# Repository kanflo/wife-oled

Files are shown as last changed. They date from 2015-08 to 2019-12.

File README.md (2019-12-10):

**Wife OLED**
==========

I wanted a display showing the current outside temperature alongside with the forecasted temperature in 8 hours.

The device subscribes to the topics `home/temperature/outside` and `home/temperature/forecast` displaying them in the left and right part of the display respectively. For readability I use a large font, [Ubuntu Condensed](http://font.ubuntu.com/#charset-condensed) in sizes 32px and 28px.

**Building**

Clone this repo:

```
git clone https://github.com/kanflo/wife-oled.git
cd wife-oled
git submodule init && git submodule update

```

Set the SSID configuration of EOR by adding the following to the file ```esp-open-rtos/include/private_ssid_config.h```:

```
#define WIFI_SSID "my ssid"
#define WIFI_PASS "my password"
```

Configure the MQTT stuff in ```mqtt_config.h```

Now ```make``` and ```make flash```

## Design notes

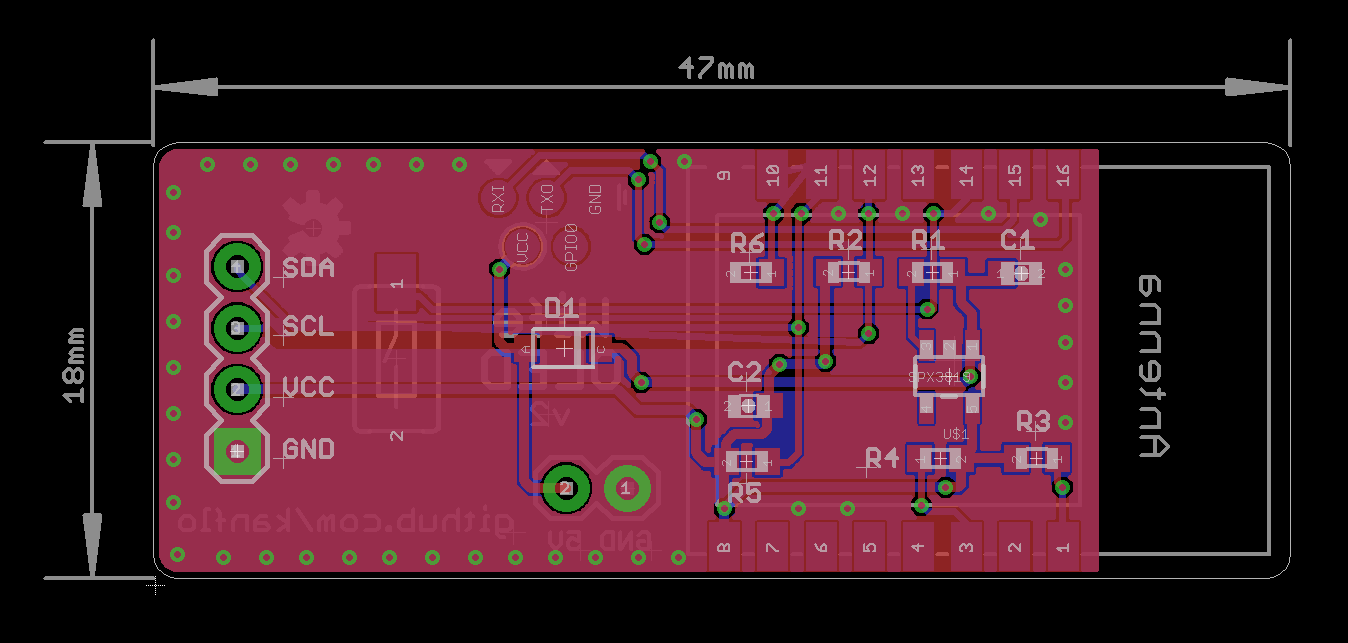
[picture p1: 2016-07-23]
hardware/WifeOLED-v2/WifeOLED-v2.png

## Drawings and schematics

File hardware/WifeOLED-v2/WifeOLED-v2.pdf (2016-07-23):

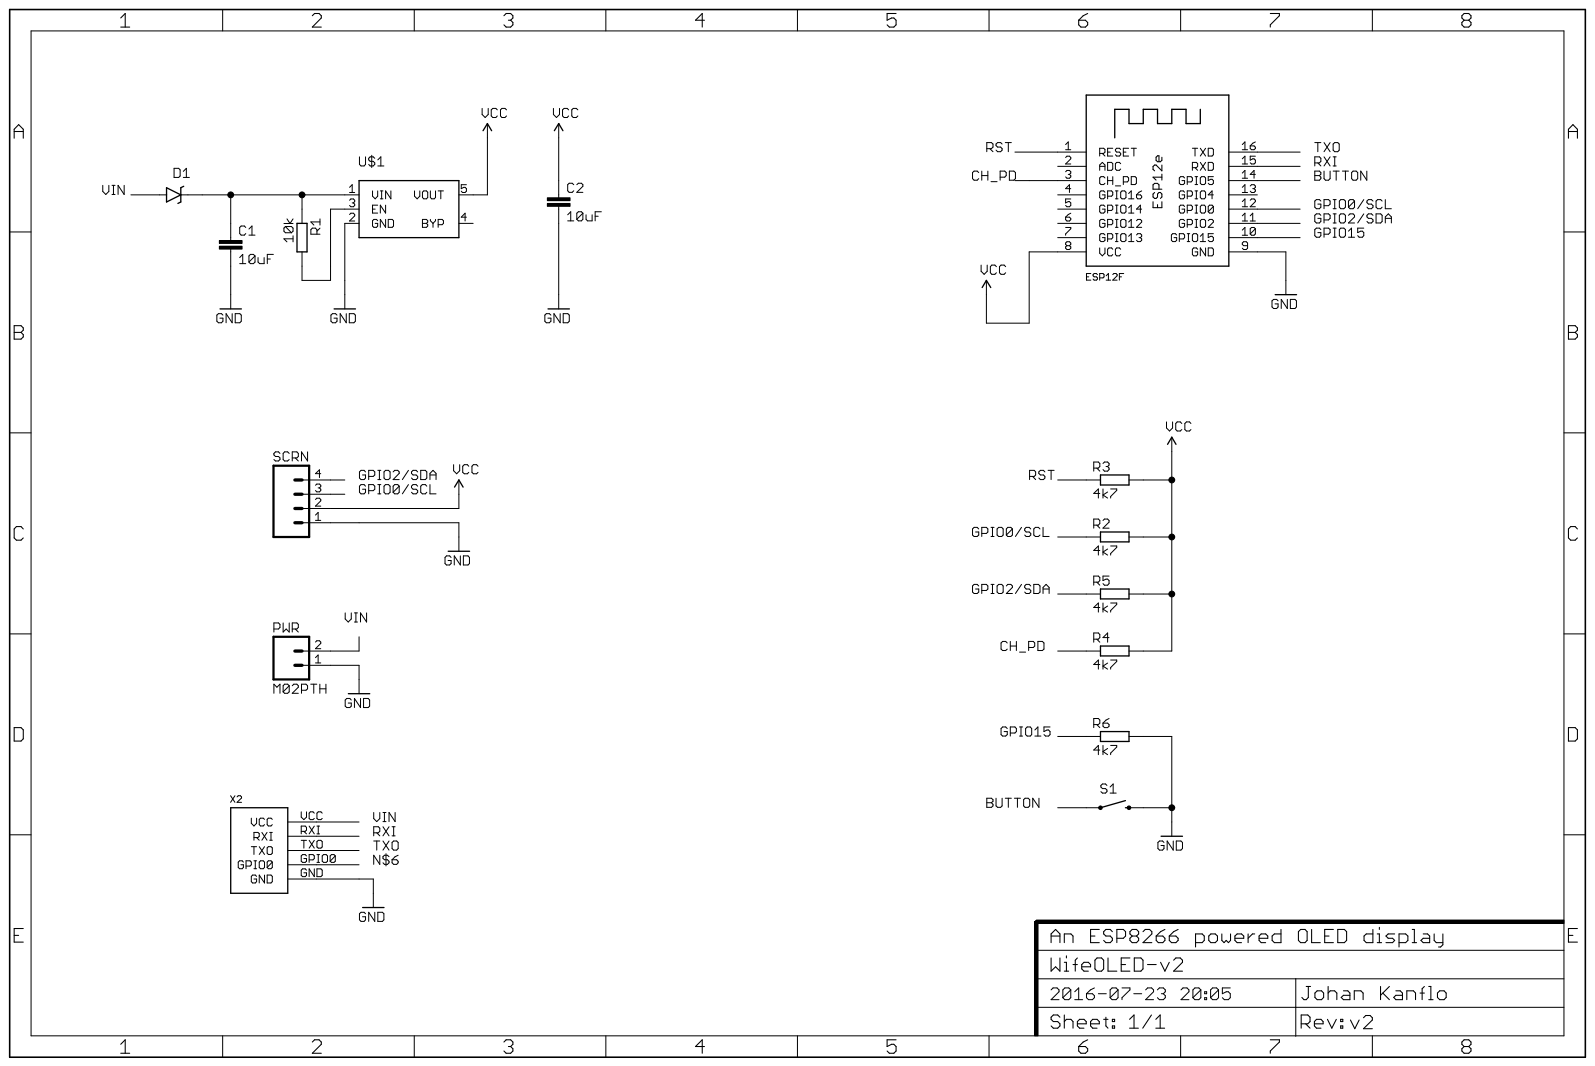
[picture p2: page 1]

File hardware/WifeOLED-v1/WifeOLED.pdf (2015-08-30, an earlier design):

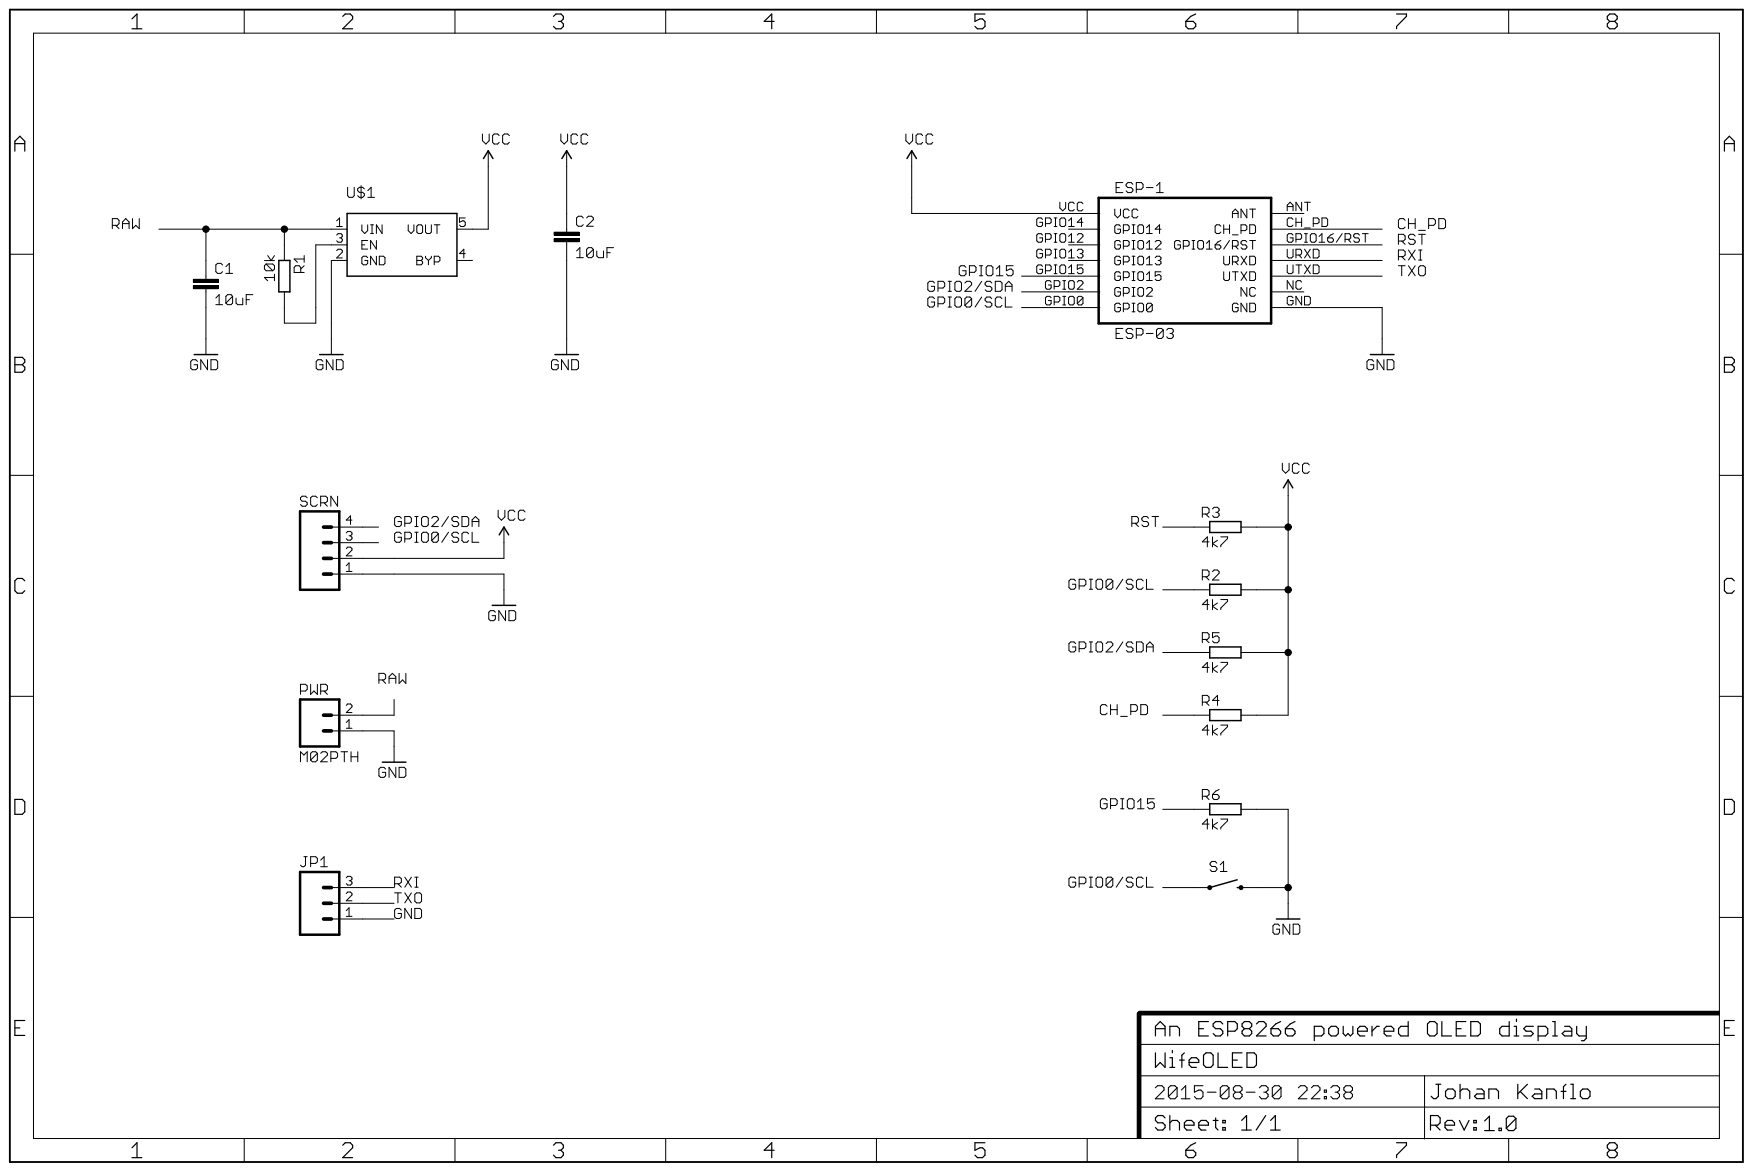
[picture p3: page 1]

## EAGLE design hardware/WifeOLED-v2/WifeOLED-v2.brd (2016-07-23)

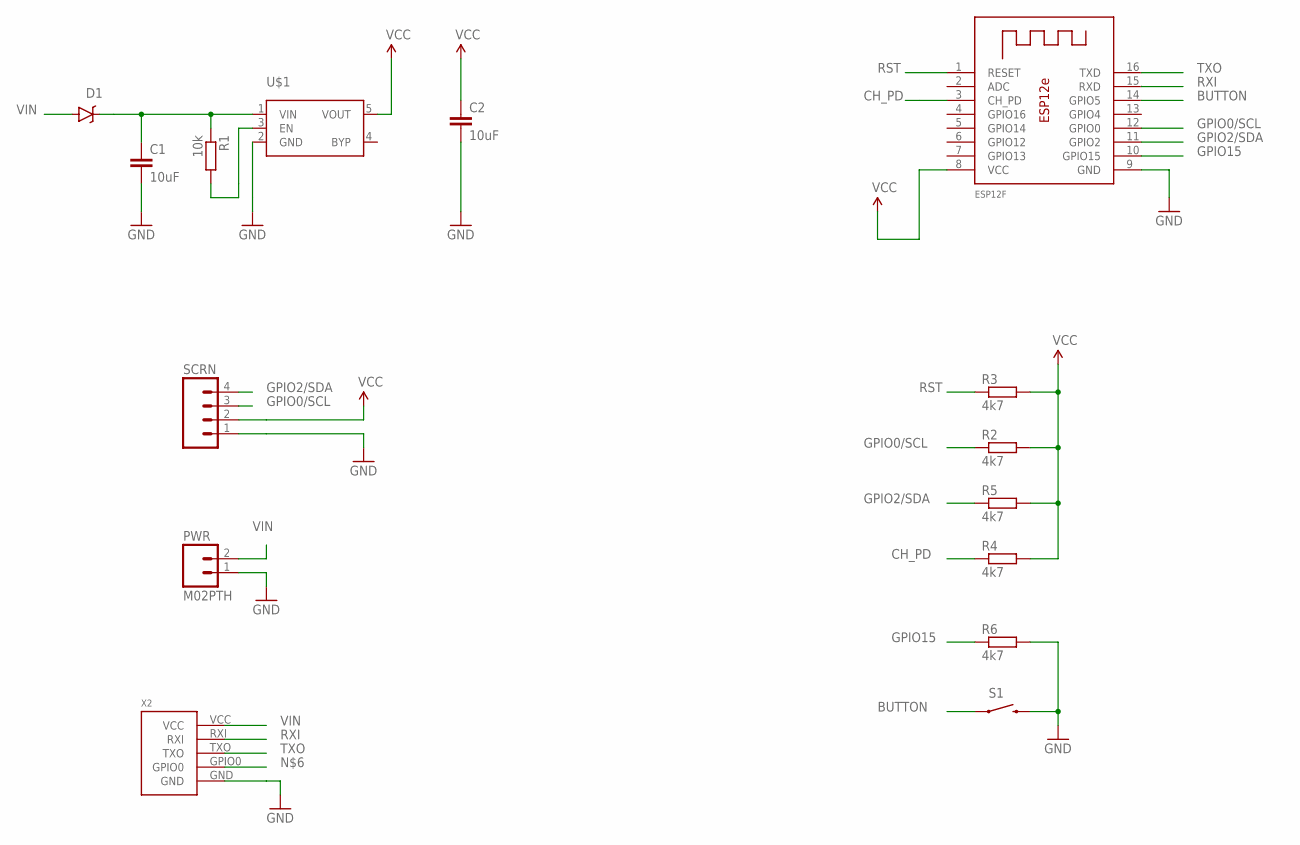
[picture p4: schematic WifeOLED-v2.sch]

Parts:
C1, C2: 10uF; 0603-CAP
D1: DIODE-SCHOTTKYSOD-123FL; SOD-123FL
ESP12F: ESP-12E
PWR: M02PTH; 1X02
R1: 10k; R0603
R2, R3, R4, R5, R6: 4k7; R0603
S1: SWITCH-MOMENTARY-2SMD-1101NE; TACTILE-SWITCH-1101NE
SCRN: M04PTH; 1X04
U$1: SPX3819; SOT23-5
X2: ESPROGESPROG-DEVICE; ESPROG

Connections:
BUTTON: ESP12F.14 (GPIO5), S1.1
CH_PD: ESP12F.3 (CH_PD), R4.1
GND: C1.2, C2.2, ESP12F.9 (GND), PWR.1, R6.2, S1.2, SCRN.1, U$1.2 (GND), X2.GND
GPIO0/SCL: ESP12F.12 (GPIO0), R2.1, SCRN.3
GPIO2/SDA: ESP12F.11 (GPIO2), R5.1, SCRN.4
GPIO15: ESP12F.10 (GPIO15), R6.1
unnamed: R1.2, U$1.3 (EN)
unnamed: C1.1, D1.C, R1.1, U$1.1 (VIN)
RST: ESP12F.1 (RESET), R3.1
RXI: ESP12F.15 (RXD), X2.RXI
TXO: ESP12F.16 (TXD), X2.TXO
VCC: C2.1, ESP12F.8 (VCC), R2.2, R3.2, R4.2, R5.2, SCRN.2, U$1.5 (VOUT)
VIN: D1.A, PWR.2, X2.VCC

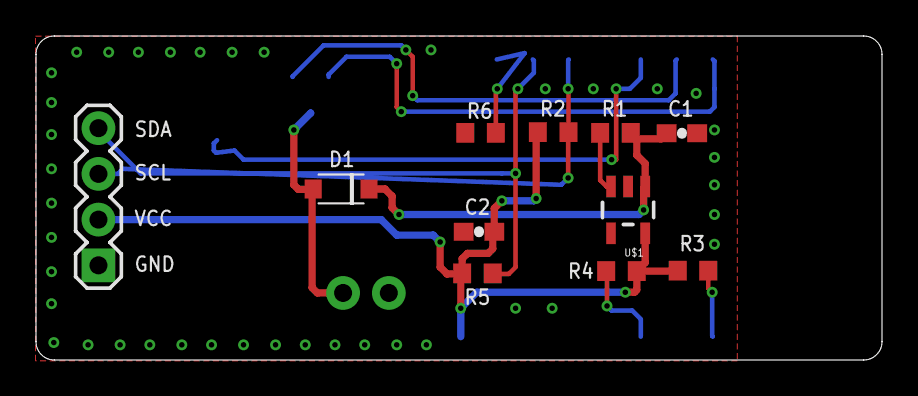
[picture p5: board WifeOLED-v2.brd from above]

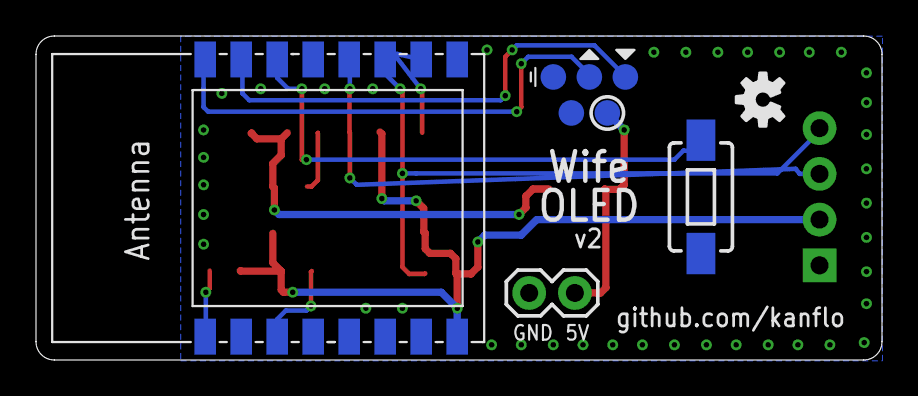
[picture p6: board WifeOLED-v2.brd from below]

Board: 2 copper layers, 47.0 x 18.0 mm, 16 parts (5 on the bottom side), 13 nets.

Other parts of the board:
U$2: OSHW-LOGO-S

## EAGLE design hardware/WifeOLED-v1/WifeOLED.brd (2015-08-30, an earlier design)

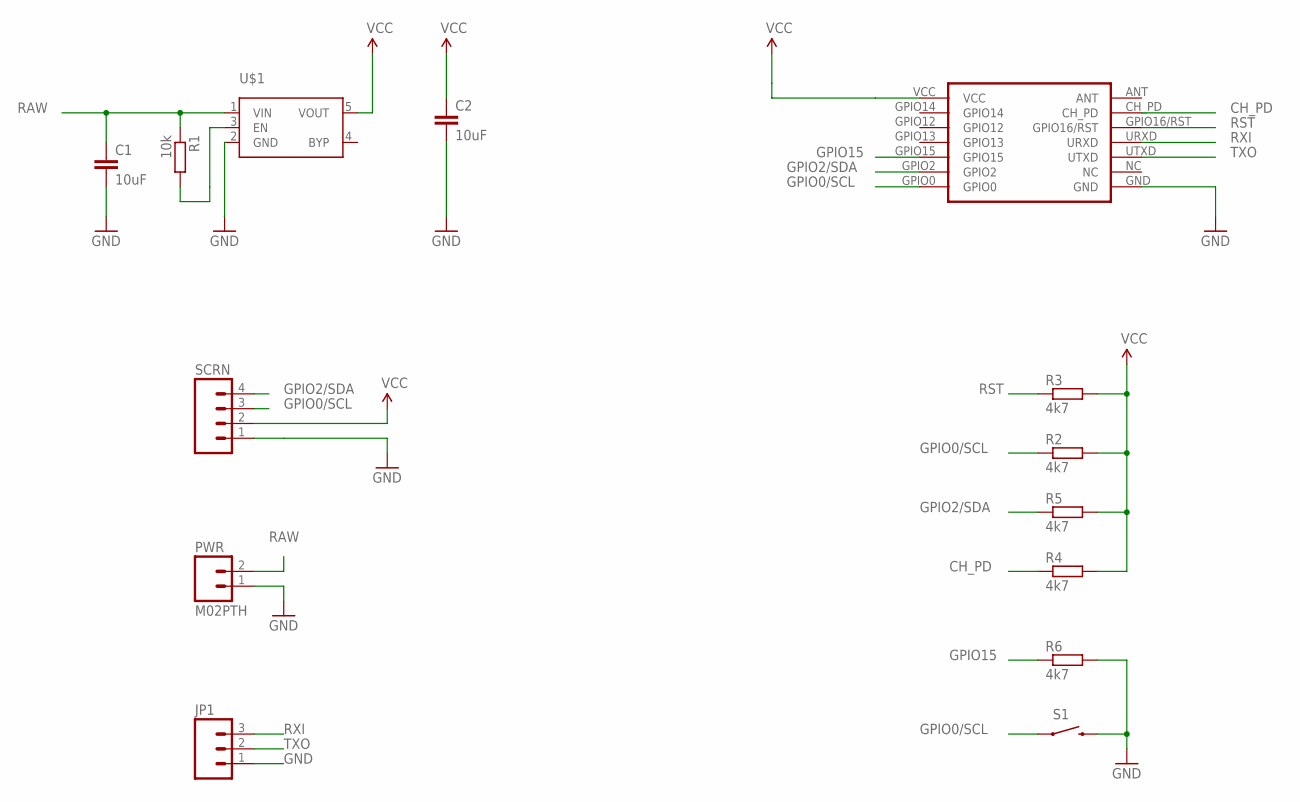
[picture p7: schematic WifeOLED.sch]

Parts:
C1, C2: 10uF; 0603-CAP
ESP-1: ESP-03
JP1: M03PTH; 1X03
PWR: M02PTH; 1X02
R1: 10k; R0603
R2, R3, R4, R5, R6: 4k7; R0603
S1: SWITCH-MOMENTARY-2SMD-1101NE; TACTILE-SWITCH-1101NE
SCRN: M04PTH; 1X04
U$1: SPX3819; SOT23-5

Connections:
CH_PD: ESP-1.CH_PD, R4.1
GND: C1.2, C2.2, ESP-1.GND, JP1.1, PWR.1, R6.2, S1.2, SCRN.1, U$1.2 (GND)
GPIO0/SCL: ESP-1.GPIO0, R2.1, S1.1, SCRN.3
GPIO2/SDA: ESP-1.GPIO2, R5.1, SCRN.4
GPIO15: ESP-1.GPIO15, R6.1
unnamed: R1.2, U$1.3 (EN)
RAW: C1.1, PWR.2, R1.1, U$1.1 (VIN)
RST: ESP-1.GPIO16/RST, R3.1
RXI: ESP-1.URXD, JP1.3
TXO: ESP-1.UTXD, JP1.2
VCC: C2.1, ESP-1.VCC, R2.2, R3.2, R4.2, R5.2, SCRN.2, U$1.5 (VOUT)

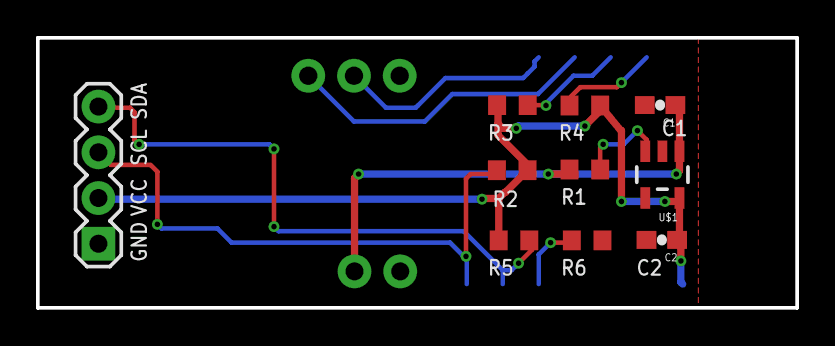
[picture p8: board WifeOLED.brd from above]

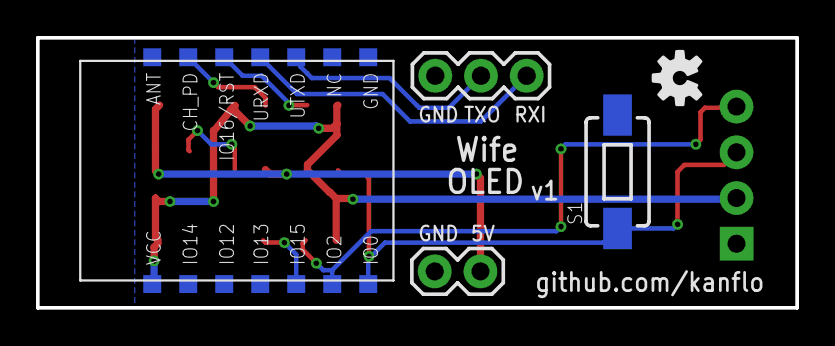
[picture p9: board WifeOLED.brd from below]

Board: 2 copper layers, 42.2 x 15.0 mm, 15 parts (5 on the bottom side), 11 nets.

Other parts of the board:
U$2: OSHW-LOGO-S

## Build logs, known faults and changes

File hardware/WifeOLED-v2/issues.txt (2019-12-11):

Issues with v2
--------------
The following issues have been identified after v2 came back from China:

X2      GPIO0 from the esprog connector is not connected to GPIO0/SCL meaning
        a manual ground is needed for espprog programming.

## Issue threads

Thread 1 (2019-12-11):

Bug in revision 2 hardware

kanflo, 2019-12-11:
GPIO0 from the esprog connector (X2) is not connected to GPIO0/SCL meaning a manual ground is needed for espprog programming.

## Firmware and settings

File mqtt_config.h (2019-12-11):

#ifndef __MQTT_CONFIG_H__
#define __MQTT_CONFIG_H__

#define MQTT_HOST "172.16.3.100"
#define MQTT_PORT 1883
#define MQTT_USER NULL
#define MQTT_PASS NULL

/** Topic to receive outside temperature */
#define OUTSIDE_TEMP_TOPIC          "home/temperature/outside"
/** Topic to receive forecasted outside temperature */
#define OUTSIDE_TEMP_FORECAST_TOPIC "home/temperature/forecast"
/** Topic to reboot device */
#define REBOOT_TOPIC                "oledthermometer/reboot"
/** A topic for managing display on, off and display fading */
/** Valid messages are 'fadein', 'fadeout', 'off' and 'on' */
#define DISPLAY_TOPIC               "oledthermometer/display"

/** Heartbeats from the display are published on this topic every
 *  HEARTBEAT_TIME_MS */
#define HEARTBEAT_TOPIC             "oledthermometer/heartbeat"
#define HEARTBEAT_TIME_MS           (60000)

#endif // __MQTT_CONFIG_H__

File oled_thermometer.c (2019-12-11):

/*

    Copyright (c) 2019 Johan Kanflo (github.com/kanflo)

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
    You should have received a copy of the GNU General Public License along
    with this program; if not, write to the Free Software Foundation, Inc.,
    51 Franklin Street, Fifth Floor, Boston, MA 02110-1301 USA.

*/

#include "espressif/esp_common.h"
#include "esp/uart.h"
#include <string.h>
#include <FreeRTOS.h>
#include <task.h>
#include <semphr.h>
#include <ssid_config.h>
#include <espressif/esp_sta.h>
#include <espressif/esp_wifi.h>
#include <paho_mqtt_c/MQTTESP8266.h>
#include <paho_mqtt_c/MQTTClient.h>
#include <i2c/i2c.h>
#include <ssd1306/ssd1306.h>
#include <fonts/fonts.h>
#include <idiota.h>
#include "font_bits.h"
#include "icon_bits.h"
#include "font.h"
#include "ssd1306_utils.h"
#include "mqtt_config.h"


/** I2C configuration */
#define I2C_BUS 0
#define SCL_PIN 0
#define SDA_PIN 2

#define GPIO_BUTTON 0
//#define GPIO_BUTTON 5
/** Pressing the button lights up the display if dimmed or off, go back to
 *  previous setting after this time
 */
#define BUTTON_ACTION_TIME_MS  (5000)
#define BUTTON_DEBOUNCE_TIME_MS  (150)

/** Size of display */
#define DISPLAY_WIDTH  (128)
#define DISPLAY_HEIGHT (32)

/** If we have not connected within this time, something might be up with the
  *  wifi driver and we reboot as a feeble attempt to fix that
  */
#define WIFI_RESTART_TIME_MS  (60000)

static const ssd1306_t dev = {
    .protocol     = SSD1306_PROTO_I2C,
    .screen       = SSD1306_SCREEN,
    .i2c_dev.bus  = I2C_BUS,
    .i2c_dev.addr = SSD1306_I2C_ADDR_0,
    .width        = DISPLAY_WIDTH,
    .height       = DISPLAY_HEIGHT
};

/* Local frame buffer */
static uint8_t buffer[DISPLAY_WIDTH * DISPLAY_HEIGHT / 8];

#define DEFAULT_FONT FONT_FACE_ROBOTO_10PT

/** Convenience macros. Cannot understant the FreeRTOS tick addiction... */
#define delay_ms(t) vTaskDelay((t) / portTICK_PERIOD_MS)
#define get_time_ms() (xTaskGetTickCount() / configTICK_RATE_HZ)

/** Mutes for display updates */
SemaphoreHandle_t display_sem;
/** A semaphose that incicates wifi connection */
SemaphoreHandle_t wifi_connected;
/** MQTT publish queue */
QueueHandle_t publish_queue;
/** Button press queue */
QueueHandle_t button_queue;

#define PUB_MSG_LEN 32

/** Shall we draw stuff on the display of should it be considered off? */
bool display_on = true;
/** Is the display dimmed? */
bool display_dimmed = false;
/** Latest received temperature */
char temperature[PUB_MSG_LEN] = {0};
/** Latest received forecasted temperature */
char forecast[PUB_MSG_LEN] = {0};
/** Kerning between the temperature characters */
uint32_t kerning = 1;

/** Should be found lurking in a header file someehere... */
#ifndef MIN
 #define MIN(a, b) ((a) < (b) ? (a) : (b))
#endif // MIN


#ifdef CONFIG_IDIOTA_SERVER
 #define IDIOTA_SERVER       CONFIG_IDIOTA_SERVER
#else
 #define IDIOTA_SERVER       "172.16.3.113"
#endif // CONFIG_IDIOTA_SERVER

#ifdef CONFIG_IDIOTA_PORT
 #define IDIOTA_PORT       CONFIG_IDIOTA_PORT
#else
 #define IDIOTA_PORT       "27532"
#endif // CONFIG_IDIOTA_PORT

#ifdef CONFIG_IDIOTA_CHECK_INTERVAL
 #define IDIOTA_CHECK_INTERVAL       CONFIG_IDIOTA_CHECK_INTERVAL
#else
 #define IDIOTA_CHECK_INTERVAL       1
#endif // CONFIG_IDIOTA_PORT

#ifdef CONFIG_NODE_ID
 #define NODE_ID       CONFIG_NODE_ID
#else
 #define NODE_ID       NULL
#endif // CONFIG_IDIOTA_PORT

#ifdef CONFIG_NODE_TYPE
 #define NODE_TYPE       CONFIG_NODE_TYPE
#else
 #define NODE_TYPE       NULL
#endif // CONFIG_IDIOTA_PORT

#ifdef CONFIG_HW_REVISION
 #define HW_REV       CONFIG_HW_REVISION
#else
 #define HW_REV       NULL
#endif // CONFIG_HW_REVISION

/** Forward declarations to keep the compiler happy */
void gpio_irq_handler(uint8_t gpio_num);
static void display_message(char *msg, bool is_error);
static const char* get_wifi_macaddr(void);


void ota_status_cb(ota_status_t status);

static ota_info ota_config = {
    .server         = IDIOTA_SERVER,
    .port           = IDIOTA_PORT,
    .check_interval = IDIOTA_CHECK_INTERVAL,
    .node_id        = NODE_ID,
    .node_type      = NODE_TYPE,
    .hw_rev         = HW_REV,
    .ota_cb         = ota_status_cb
};

void ota_status_cb(ota_status_t status)
{
    switch(status) {
        case OTA_DNS_LOOKUP_FAILED:
            printf("Error: DNS lookup has failed\n");
            break;
        case OTA_SOCKET_ALLOCATION_FAILED:
            printf("Error: could not allocate OTA socket\n");
            break;
        case OTA_SOCKET_CONNECTION_FAILED:
            printf("Error: failed to connect to server %s:%s\n", IDIOTA_SERVER, IDIOTA_PORT);
            break;
        case OTA_SHA256_MISMATCH:
            printf("Error: downloaded SHA256 does not match downloaded binary\n");
            break;
        case OTA_REQUEST_SEND_FAILED:
            printf("Error: could not send OTA HTTP request\n");
            break;
        case OTA_DOWNLOAD_SIZE_MISMATCH:
            printf("Error: OTA download failed\n");
            break;
        case OTA_ONE_SLOT_ONLY:
            printf("Error: rboot has only one slot configured, cannot run OTA\n");
            break;
        case OTA_FAIL_SET_NEW_SLOT:
            printf("Error: rboot failed to switch\n");
            break;
        case OTA_IMAGE_VERIFY_FAILED:
            printf("Error: rboot verification failed\n");
            break;
        case OTA_START:
            printf("OTA started\n");
            break;
        case OTA_RUNNING:
            //printf("OTA running\n");
            break;
        case OTA_COMPLETED:
            printf("OTA successful\n");
            break;
        case OTA_IDLE:
            break;
    }
}

/**
 * @brief      Button IRQ handler
 *
 * @param[in]  gpio_num  The gpio number
 */
void gpio_irq_handler(uint8_t gpio_num)
{
    uint32_t now_ms = xTaskGetTickCountFromISR() * portTICK_PERIOD_MS;
    (void) xQueueSendToBackFromISR(button_queue, &now_ms, NULL);
}

/**
 * @brief      Restart the system
 */
static void restart(void)
{
    display_message("Restarting", true);
    /** In case we hang in the restart */
    ssd1306_fade_out(&dev);
    sdk_system_restart();
    display_message("Restart failed", true);
    while(1);
}

/**
 * @brief      Lazy function for clearing the display
 */
static void clear_display(void)
{
    ssd1306_fill_rectangle(&dev, buffer, 0, 0, DISPLAY_WIDTH, DISPLAY_HEIGHT, OLED_COLOR_BLACK);
}

/**
 * @brief      Lazy function for refreshing the display
 */
static void refresh_display(void)
{
    ssd1306_load_frame_buffer(&dev, buffer);
}
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

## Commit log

2015-08-30 Added schematics and gerbers.
    [WifeOLED.brd, WifeOLED.sch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]
2016-07-23 Renamed eagle -> hardware
    [WifeOLED.brd, WifeOLED.sch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]
2016-07-23 Moved eagle stuff into v1 directory
    [WifeOLED.brd, WifeOLED.sch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]
2016-07-23 Wife OLED version 2 using ESP-12 instead of ESP-03
    [WifeOLED-v2.brd, WifeOLED-v2.sch]
2019-12-11 Tried to make wifi reconnects more stable, added gpio button handler

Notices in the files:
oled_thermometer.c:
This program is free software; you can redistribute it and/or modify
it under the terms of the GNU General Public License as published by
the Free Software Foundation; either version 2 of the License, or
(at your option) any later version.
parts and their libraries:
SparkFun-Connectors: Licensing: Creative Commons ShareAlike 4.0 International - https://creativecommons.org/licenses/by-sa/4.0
